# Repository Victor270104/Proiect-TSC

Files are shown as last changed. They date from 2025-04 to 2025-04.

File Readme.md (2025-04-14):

# OpenBook

**Autor:** Sandu Victor, 332CC

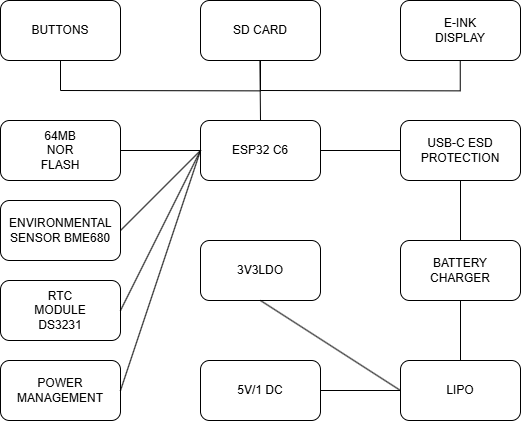
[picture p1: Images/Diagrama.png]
Diagrama Proiect


---

## 1. Descriere generală

Acest proiect propune o platformă hardware pentru dezvoltarea de aplicații IoT și afișare e-paper, cu consum redus de energie. Elementul central este microcontrollerul **ESP32-C6-WROOM-1**, care oferă conectivitate Wi-Fi 6 și Bluetooth Low Energy. Sistemul este proiectat pentru a funcționa atât conectat la USB-C, cât și alimentat de la o baterie Li-Po.

---

## 2. Caracteristici cheie

- **Alimentare prin USB-C**: Simplifică programarea și încărcarea bateriei.
- **Microcontroller ESP32-C6**: Include nucleu RISC-V, Wi-Fi 6, BLE și memorie flash internă de 8MB.
- **Senzori integrați**: BME688 (temperatură, umiditate, presiune, gaze) și DS3231 (ceas de timp real).
- **Stocare suplimentară**:
  - Card SD (SPI)
  - Memorie NOR Flash (W25Q512)
- **Afișaj E-Paper**: Consum ultra-redus, actualizare doar la nevoie.
- **Monitorizare baterie**: MAX17048 pentru nivelul de încărcare.

---

## 3. Structură hardware (sumar)

- **USB-C** și protecții ESD (varistori, diodă TVS).
- **Circuit încărcare Li-Po** cu MCP73831.
- **Regulator LDO** pentru 3.3V stabil.
- **Microcontrollerul ESP32-C6-WROOM-1** (SPI, I2C, GPIO).
- **Senzori**:
  - BME688 (I2C)
  - DS3231 (I2C)
- **Memorii**:
  - Card SD (SPI)
  - W25Q512 (SPI)
- **E-Paper** cu driver SPI și alimentare comutabilă (MOSFET).
- **Butoane** de RESET și BOOT.

*(Diagrama de mai sus este inclusă din `Images/Diagrama.png`.)*

---

## 4. Bill of Materials (BOM)

| Component  | Supplier Link | Datasheet |
|---|---|---|
| 112A-TAAR-R03 | [Model](https://store.comet.srl.ro/Catalogue/Product/43497/) | [Datasheet](https://www.snapeda.com/parts/112A-TAAR-R03/Attend/datasheet/) |
| 744043680 | [Model](https://ro.mouser.com/ProductDetail/Wurth-Elektronik/744043680?qs=PGXP4M47uW6VkZq%252BkzjrHA%3D%3D) | [Datasheet](https://www.we-online.com/components/products/datasheet/744043680.pdf) |
| BD5229G-TR | [Model](https://componentsearchengine.com/part-view/BD5229G-TR/ROHM%20Semiconductor) | [Datasheet](https://fscdn.rohm.com/en/products/databook/datasheet/ic/power/voltage_detector/bd52xxg-e.pdf) |
| Capacitor 0402 | [Model](https://ro.mouser.com/c/passive-components/capacitors/ceramic-capacitors/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) | [Datasheet](https://componentsearchengine.com/Datasheets/2/CC0402MRX5R5BB106.pdf) |
| CPH3225A | [Model](https://www.snapeda.com/parts/CPH3225A/Seiko+Instruments/view-part/?ref=snap) | [Datasheet](https://www.snapeda.com/parts/CPH3225A/Seiko%20Instruments/datasheet/) |
| Custom Button | [Model](https://industry.panasonic.com/global/en/products/control/switch/light-touch/number/evqpuj02k) | [Datasheet](https://industry.panasonic.com/global/en/downloads?tab=catalog&small_g_cd=203&part_no=EVQPUJ02K) |
| DS3231SN | [Model](https://www.snapeda.com/parts/DS3231SN%23/Analog+Devices/view-part/?ref=eda) | [Datasheet](https://www.snapeda.com/parts/DS3231SN%23/Analog%20Devices/datasheet/) |
| ESP32 WROVER 0805 Capacitor | [Model]() | [Datasheet]() |
| ESP32 WROVER BME680 Sensor | [Model](https://www.snapeda.com/parts/BME680/Bosch/view-part/?welcome=home) | [Datasheet](https://www.bosch-sensortec.com/media/boschsensortec/downloads/datasheets/bst-bme680-ds001.pdf) |
| ESP32 WROVER MCP73831 Power Management | [Model](https://www.snapeda.com/parts/BME680/Bosch/view-part/?welcome=home) | [Datasheet](https://www.snapeda.com/parts/MCP73831T-2ACI/OT/Microchip/datasheet/) |
| ESP32C6 Varistor 1812 | [Model]() | [Datasheet]() |
| ESP32C6 WROOM-1-N8| [Model](https://www.snapeda.com/parts/ESP32-C6-WROOM-1-N8/Espressif+Systems/view-part/?ref=eda) | [Datasheet](https://www.snapeda.com/parts/ESP32-C6-WROOM-1-N8/Espressif%20Systems/datasheet/) |
| FH34SRJ-24S-0.5SH | [Model](https://ro.mouser.com/ProductDetail/Hirose-Connector/FH34SRJ-24S-0.5SH99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) | [Datasheet](https://www.snapeda.com/parts/FH34SRJ-24S-0.5SH(99)/Hirose%20Connector/datasheet/) |
| LED Chip 0603 | [Model](https://www.snapeda.com/parts/KP-1608SURCK/Kingbright/view-part/?ref=search&t=LED%200603) | [Datasheet](https://www.snapeda.com/parts/KP-1608SURCK/Kingbright/datasheet/) |
| MAX17048G+T10 | [Model](https://www.snapeda.com/parts/MAX17048G+T10/Analog+Devices/view-part/?ref=eda) | [Datasheet](https://www.snapeda.com/parts/MAX17048G+T10/Analog%20Devices/datasheet/) |
| MBR0530 Schottky Diode | [Model](https://www.snapeda.com/parts/MBR0530/Onsemi/view-part/?ref=snap) | [Datasheet](https://www.snapeda.com/parts/MBR0530/ON%20Semiconductor/datasheet/) |
| PGB1010603MR | [Model](https://www.snapeda.com/parts/PGB1010603MR/Littelfuse/view-part/?ref=eda) | [Datasheet](https://www.snapeda.com/parts/PGB1010603MR/Littelfuse%20Inc./datasheet/) |
| QWIIC Connector | [Model](https://www.snapeda.com/parts/PRT-14417/SparkFun/view-part/) | [Datasheet](https://www.snapeda.com/parts/PRT-14417/SparkFun%20Electronics/datasheet/) |
| RCL CPOL 3528 | [Model](https://www.snapeda.com/parts/CPH3225A/Seiko+Instruments/view-part/?ref=eda) | [Datasheet](https://s3.amazonaws.com/snapeda/datasheet/TAJB475K025RNJ_AVX.pdf) |
| Resistor 0402 | [Model](https://grabcad.com/library/resistor-0402-1) | [Datasheet](https://www.yageo.com/upload/media/product/products/datasheet/rchip/PYu-RC_Group_51_RoHS_L_12.pdf) |
| SI1308EDL-T1-GE3 MOSFET | [Model](https://www.snapeda.com/parts/SI1308EDL-T1-GE3/Vishay+Siliconix/view-part/?welcome=home&ref=eda) | [Datasheet](https://www.snapeda.com/parts/SI1308EDL-T1-GE3/Vishay%20Siliconix/datasheet/) |
| SJ | [Model](https://grabcad.com/library/solder-jumpers-1) | [Datasheet]() |
| USB4110-GF-A | [Model](https://componentsearchengine.com/part-view/USB4110-GF-A/GCT%20(GLOBAL%20CONNECTOR%20TECHNOLOGY)) | [Datasheet](https://gct.co/files/drawings/usb4110.pdf) |
| USBLC6-2SC6Y | [Model](https://www.snapeda.com/parts/USBLC6-2SC6Y/STMicroelectronics/view-part/?welcome=home&ref=eda) | [Datasheet](https://www.snapeda.com/parts/USBLC6-2SC6Y/STMicroelectronics/datasheet/) |
| W25Q512JVEIQ | [Model](https://www.snapeda.com/parts/W25Q512JVEIQ/Winbond+Electronics/view-part/?ref=eda) | [Datasheet](https://www.winbond.com/resource-files/W25Q512JV%20SPI%20RevB%2006252019%20KMS.pdf) |
| XC6220A331MR-G | [Model](https://componentsearchengine.com/part-view/XC6220A331MR-G/Torex) | [Datasheet](https://product.torexsemi.com/system/files/series/xc6220.pdf) |

## 5. Mapare pini ESP32-C6

| Component | ESP32-C6 Pin(s) | Interface | Purpose |
|---|---|---|---|
| **E-Paper Display** | IO7 (MOSI), IO6 (SCK), IO10 (CS), IO5 (DC), IO23 (RST), IO3 (BUSY) | SPI | Transfers image data to the display and controls its state. |
| **MicroSD Card** | IO7 (MOSI), IO6 (SCK), IO4 (SS_SD), IO2 (MISO) | SPI | Allows storage and retrieval of e-book files. |
| **Environmental Sensor (BME688)** | IO21 (SDA), IO22 (SCL) | I2C | Reads temperature, humidity, pressure, and air quality data. |
| **RTC Module (DS3231)**  | IO21 (SDA), IO22 (SCL), IO18 (RST), IO1 (32KHz), IO0 (INT_RTC) | I2C | Keeps track of time even when ESP32 is off. |
| **External NOR Flash** | IO11 (CS), IO6 (SCK), IO2 (MISO), IO7 (MOSI) | SPI | Provides additional storage for application data. |
| **Battery Monitoring** | IO21 (SDA), IO22 (SCL) | I2C | Reads battery voltage and charge status. |
| **USB-C Connection** | GPIOs through voltage regulation | USB | Powers and programs the ESP32-C6. |
| **Control Buttons** | IO9 (BOOT), IO15 (CHANGE), EN (RESET) | GPIO | User input for device interactions. |
|

## 6. Consum de energie (exemplu)

| Component | Current Draw (mA) | Voltage (V) | Power (mW) |
|---|---|---|---|
| ESP32-C6 (Wi-Fi active)  |200 |3.3 |660
| E-Paper Display (Updating) | 40 | 3.3 | 132 |
| BME688 Sensor (Measuring)| 3.1 | 3.3 | 10.23 |
| RTC Module (Active) | 0.15 | 3.3 | 0.495 |
| SD Card (Active) | 50 | 3.3 | 165 |
| Externar NOR Flash | 25 | 3.3 | 82.5 |
| Total Estimated Power Consumption | ~318.5mA | 3.3 | 1050.72 |

## 7. Descriere functionala hardware 

###  Arhitectura Hardware

Sistemul este bazat pe microcontrollerul **ESP32-C6-WROOM-1**, cu conectivitate Wi-Fi 6 și BLE, gândit pentru funcționare autonomă și consum redus de energie. Dispozitivul este alimentat de la o baterie Li-Po și poate fi programat prin USB-C. Componentele sunt interconectate prin SPI, I2C și GPIO.

---

### Alimentare și management baterie

- **USB-C Connector & ESD Protection**  
  Conector: `USB4110-GF-A`  
  Protecție ESD: `USBLC6-2SC6Y`

- **LDO Voltage Regulator**  
  Asigură 3.3V stabil pentru întreaga placă

- **Li-Po Battery Charger**  
  MCP73831 – circuit dedicat pentru încărcarea bateriei

- **Battery Gauge (MAX17048)**  
  Măsoară nivelul bateriei și comunică prin I2C

---

### Microcontroller principal

- **ESP32-C6-WROOM-1-N8**  
  RISC-V MCU cu Wi-Fi 6, BLE, 8MB flash intern  
  Rol: control central, comunicare cu senzori, logare, afișare

---

### Stocare

- **SD Card** – pentru loguri de date, firmware, fișiere
- **W25Q512 NOR Flash** – pentru memorie suplimentară SPI (64Mbit)

---

### Senzori & Ceas

- **BME688** – măsoară temperatură, umiditate, presiune și gaze (I2C)
- **DS3231** – ceas de timp real, cu precizie ridicată (I2C)

---

### Afișaj

- **E-Paper Driver + Conector**  
  Conectat prin SPI, controlat de ESP32  
  Alimentarea este comutabilă cu un MOSFET (SI1308EDL)

---

### Control și testare

- **Reset / Boot Buttons**
- **Qwiic/Stemma QT Connector** – extensii I2C
- **Test Pads** – debugging ușor

---

### Protecții

- **TVS Diodes**: `PGB1010603MR` – protecție ESD pe linii sensibile
- **Varistori**: protecție la supratensiuni

---

## 9. Note Adiționale de Proiectare

### Ajustări ale Footprint-urilor

- **Diode (SMD-Hole)**: Footprint-ul inițial avea orificiile pad-urilor prea mici, ceea ce ar fi putut cauza probleme la lipire. Dimensiunea pad-urilor a fost actualizată la **35mil x 190mil** pentru a asigura o producibilitate bună și o conexiune electrică fiabilă.

- **U4 – MAX17048G+T10**: Calea de alimentare VBAT a fost proiectată cu o lățime de **0,3 mm**, pe baza constrângerilor de implementare. Totuși, în footprint, pinii aveau numai **0,27 mm**, cauzând asimetrie și rutare inconsistentă. Dimensiunile pinilor au fost ajustate pentru a se potrivi cu lățimea traseului și a menține simetria designului.

---

### Rutare & Plan de Masă

- **Traseele de alimentare** au fost rutate exclusiv pe stratul superior (Top Layer), necesitând aproximativ **150 de via-uri** pentru a permite rutarea semnalelor pe stratul inferior (Bottom Layer).
- **Planul de masă (GND)** a fost adăugat după ce rutarea a fost finalizată, aplicându-se atât pe stratul superior, cât și pe cel inferior, pentru a obține o împământare cu impedanță redusă și pentru a diminua interferențele EMI.

---

### Poziționarea Componentelor

- **Porturile externe** au fost aliniate cu atenție în raport cu carcasa personalizată OpenBook, pentru a asigura o potrivire corectă și acces ușor.
- **Pad-urile de test (TP)** au fost plasate în apropierea marginilor plăcii și în zone accesibile, pentru a facilita depanarea și testarea.
- **Condenzatoarele de decuplare 100nF** au fost poziționate cât mai aproape de pinii de alimentare ai circuitelor integrate, în conformitate cu practicile standard de reducere a zgomotului.

---

### Probleme de Schematice & Modele 3D

- **Net „GND1”**: A apărut în schematică un net denumit „GND1”, însă acesta nu era vizibil și nu era funcțional conectat la masă. Se presupune că a fost un artefact apărut în timpul procesului de proiectare.
- **Ordinea pinilor la componente 3D**: După finalizarea rutării, actualizarea modelelor 3D a inversat ordinea pinilor la anumite componente cu 2 pini, rupând conexiunile existente. S-a rezolvat prin rotirea acelor modele cu **180°** și realinierea pinilor.

---

### Carcasă & Integrare 3D

- A fost creată o versiune alternativă a carcasei OpenBook, care include o **culoare personalizată** pentru un aspect unic.
- Componentele 3D au fost importate în două moduri diferite, în funcție de frecvența cu care apăreau în schematică.

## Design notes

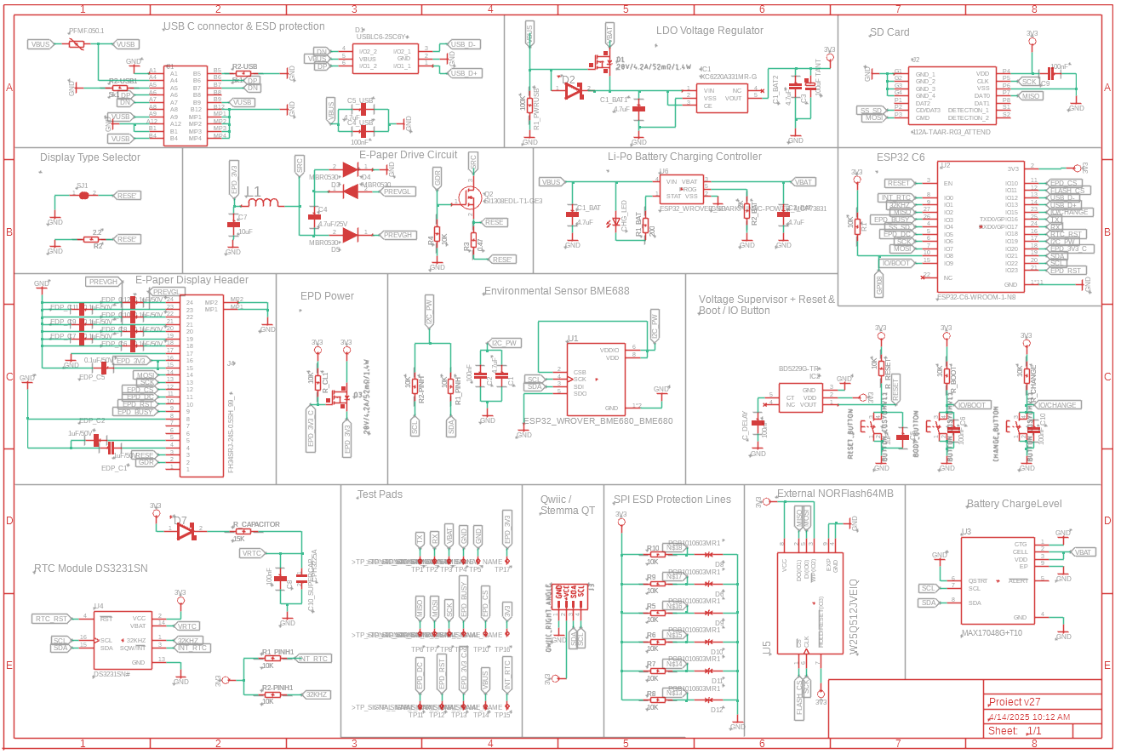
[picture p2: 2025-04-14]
Images/Schematic.png

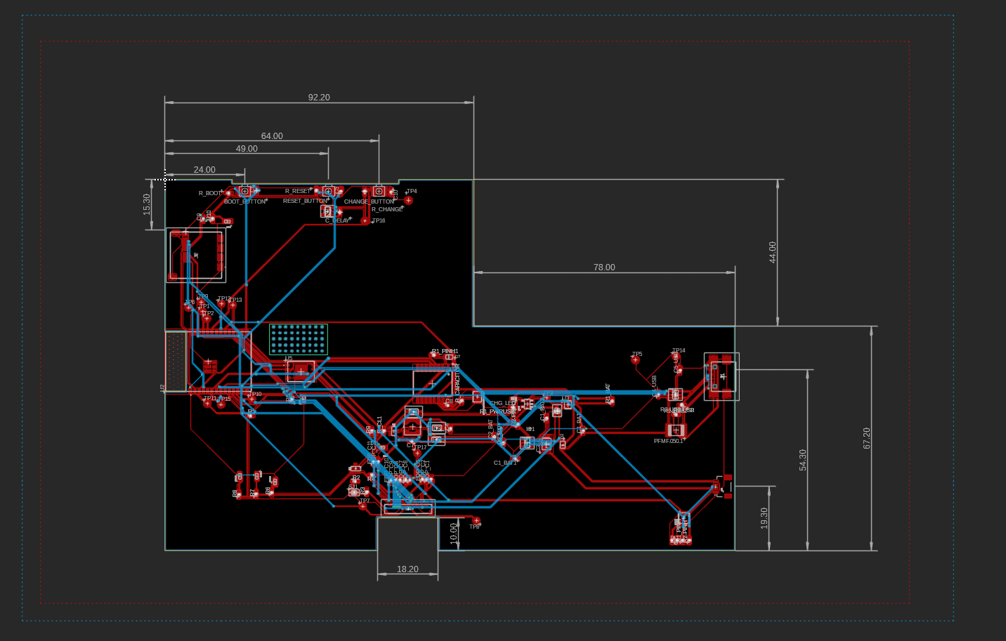
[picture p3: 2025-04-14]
Images/2D.png

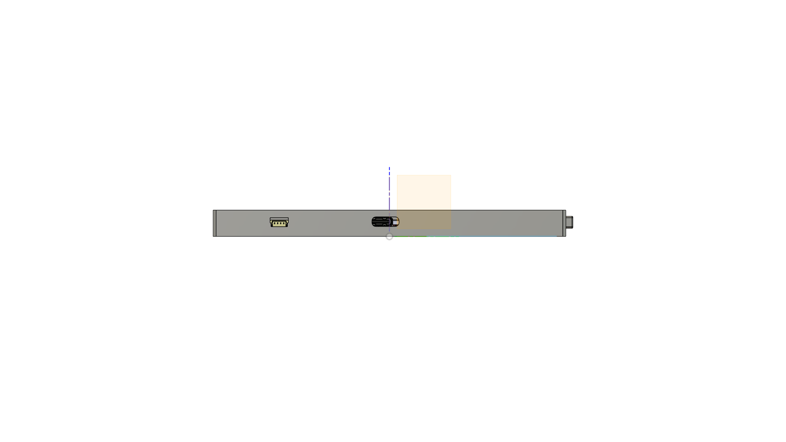
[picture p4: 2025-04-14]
Images/ports.png

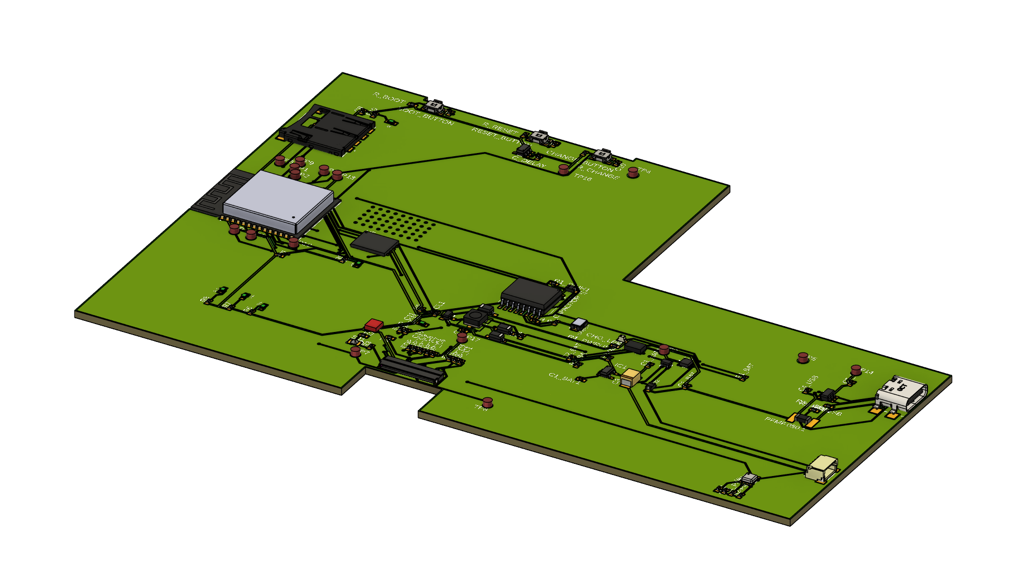
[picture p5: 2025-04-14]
Images/3D.png

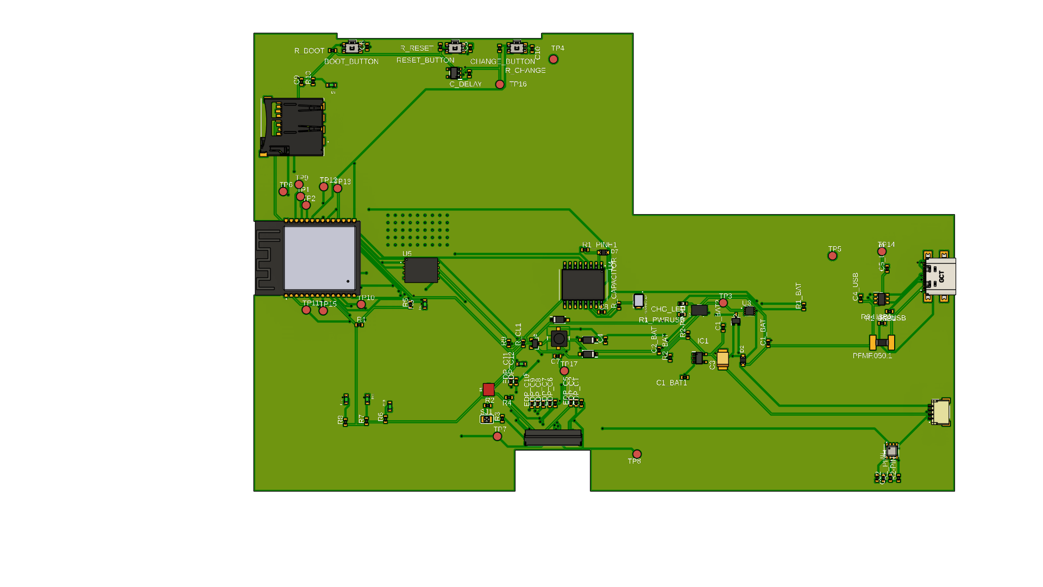
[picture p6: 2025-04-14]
Images/3D TOP.png

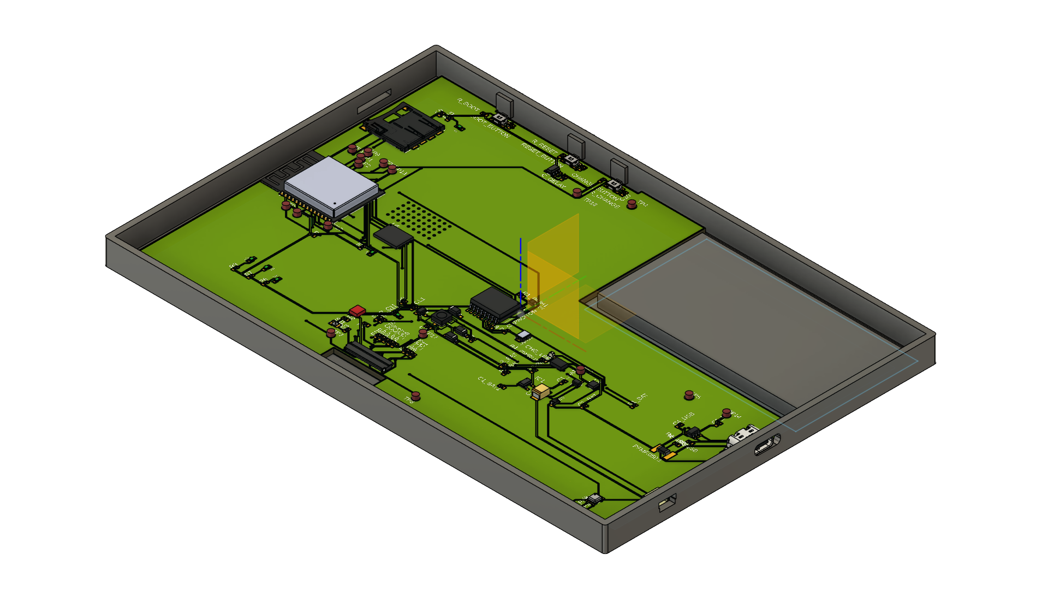
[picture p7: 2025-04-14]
Images/enclosed.png

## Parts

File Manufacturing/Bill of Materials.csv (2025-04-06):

Qty | Value | Device | Package | Parts | Description | ARROW_PART_NUMBER | ARROW_PRICE-STOCK | AVAILABILITY | CHECK_PRICES | COPYRIGHT | DESCRIPTION | HEIGHT | MANUFACTURER_NAME | MANUFACTURER_PART_NUMBER | MF | MFR_NAME | MOUSER_PART_NUMBER | MOUSER_PRICE-STOCK | MOUSER_TESTING_PART_NUMBER | MOUSER_TESTING_PRICE-STOCK | MP | PACKAGE | POPULARITY | PRICE | PROD_ID | PURCHASE-URL | SNAPEDA_LINK | SPICEMODEL | SPICEPREFIX | VALUE
1 |  | ADAFRUIT_LEDCHIP-LED0603 | ADAFRUIT_CHIP-LED0603 | CHG_LED | LED
1 |  | SJ | SJ | SJ1 | SMD solder JUMPER |  |  |  |  |  |  |  |  |  |  |  |  |  |  |  |  |  | 3
8 | 0.1uF/50V | EAGLE-LTSPICE_C | ESP32_WROVER_EAGLE-LTSPICE_C0402 | EDP_C5, EDP_C6, EDP_C7, EDP_C8, EDP_C9, EDP_C10, EDP_C11, EDP_C12 | CAPACITOR, European symbol
1 | 0.47 | ESP32_WROVER_EAGLE-LTSPICE_R | ESP32_WROVER_EAGLE-LTSPICE_R0402 | R3 | RESISTOR, European symbol
1 | 100K | ESP32_WROVER_EAGLE-LTSPICE_R | ESP32_WROVER_EAGLE-LTSPICE_R0402 | R1_PWRUSB | RESISTOR, European symbol
7 | 100nF | EAGLE-LTSPICE_C | ESP32_WROVER_EAGLE-LTSPICE_C0402 | C2, C4_USB, C6, C8, C9, C10, C_DELAY | CAPACITOR, European symbol
1 | 100uF TANT | RCL_CPOL-EUCT3528 | RCL_CT3528 | C3 | POLARIZED CAPACITOR, European symbol |  |  |  |  |  |  |  |  |  |  |  |  |  |  |  |  |  | 0 |  |  |  |  |  | C
16 | 10K | ESP32_WROVER_EAGLE-LTSPICE_R | ESP32_WROVER_EAGLE-LTSPICE_R0402 | R1, R1_PINH, R1_PINH1, R2-PINH, R2-PINH1, R4, R5, R6, R7, R8, R9, R10, R_BOOT, R_CHANGE, R_CL1, R_RESET | RESISTOR, European symbol
1 | 10uF | ESP32_WROVER_EAGLE-LTSPICE_CC0402 | ESP32_WROVER_EAGLE-LTSPICE_C0402 | C7 | CAPACITOR, European symbol |  |  |  |  |  |  |  |  |  |  |  |  |  |  |  |  |  |  |  |  |  |  | NONE | C
1 | 112A-TAAR-R03_ATTEND | 112A-TAAR-R03_ATTEND | 112ATAARR03ATTEND | J2 | Micro SD Card Socket, Push-Push Type, Top Mount, SMT, H=1.83mm, 10u |  |  |  |  |  | Micro SD Card Socket | Push-Push Type | Top Mount | SMT | H=1.83mm | 10u | 1.9mm | ATTEND | 112A-TAAR-R03 ATTEND
1 | 15K | ESP32_WROVER_EAGLE-LTSPICE_R | ESP32_WROVER_EAGLE-LTSPICE_R0402 | R_CAPACITOR | RESISTOR, European symbol
1 | 1uF | EAGLE-LTSPICE_C | ESP32_WROVER_EAGLE-LTSPICE_C0402 | C5 | CAPACITOR, European symbol
2 | 1uF/50V | EAGLE-LTSPICE_C | ESP32_WROVER_EAGLE-LTSPICE_C0402 | EDP_C1, EDP_C2 | CAPACITOR, European symbol
1 | 2.2 | ESP32_WROVER_EAGLE-LTSPICE_R | ESP32_WROVER_EAGLE-LTSPICE_R0402 | R2 | RESISTOR, European symbol
1 | 200 | ESP32_WROVER_EAGLE-LTSPICE_R | ESP32_WROVER_EAGLE-LTSPICE_R0402 | R1_BAT | RESISTOR, European symbol
2 | 20V/4.2A/52m?/1.4W | ESP32_WROVER_SPARKFUN-DISCRETESEMI_MOSFET_PCH-DMG2305UX-7 | ESP32_WROVER_SPARKFUN-DISCRETESEMI_SOT23-3 | Q1, Q3 | P-channel MOSFETs |  |  |  |  |  |  |  |  |  |  |  |  |  |  |  |  |  |  |  | TRAN-14388 |  |  |  |  | 20V/4.2A/52m?/1.4W
1 | 2K | ESP32_WROVER_EAGLE-LTSPICE_R | ESP32_WROVER_EAGLE-LTSPICE_R0402 | R2_BAT | RESISTOR, European symbol
4 | 4.7uF | EAGLE-LTSPICE_C | ESP32_WROVER_EAGLE-LTSPICE_C0402 | C1, C1_BAT1, C1_BAT2, C5_USB | CAPACITOR, European symbol
2 | 4.7uF | ESP32_WROVER_EAGLE-LTSPICE_CC0402 | ESP32_WROVER_EAGLE-LTSPICE_C0402 | C1_BAT, C2_BAT | CAPACITOR, European symbol |  |  |  |  |  |  |  |  |  |  |  |  |  |  |  |  |  |  |  |  |  |  | NONE | C
1 | 4.7uF/25V | ESP32_WROVER_EAGLE-LTSPICE_CC0402 | ESP32_WROVER_EAGLE-LTSPICE_C0402 | C4 | CAPACITOR, European symbol |  |  |  |  |  |  |  |  |  |  |  |  |  |  |  |  |  |  |  |  |  |  | NONE | C
2 | 5k1 | ESP32_WROVER_EAGLE-LTSPICE_R | ESP32_WROVER_EAGLE-LTSPICE_R0402 | R2-USB, R2-USB1 | RESISTOR, European symbol
1 | 744043680IND_4828-WE-TPC_WRE | 744043680IND_4828-WE-TPC_WRE | IND_4828-WE-TPC_WRE | L1 |  |  |  |  |  | Copyright (C) 2024 Ultra Librarian. All rights reserved. |  |  |  | 744043680 |  | Wurth Electronics
1 | BD5229G-TR | BD5229G-TR | SOT95P280X125-5N | IC2 | Voltage Detector with Adjustable Delay Time: CMOS processes are utilized to develop high precision, low current consumption CMOS reset ICs that allow arbitrary setting of the delay time. The extensive lineup includes both Nch Open Drain and CMOS output types in a wide range of detection voltages (from 2.3V to 6.0V, in 0.1V steps), enabling selection of the ideal solution based on customer requirements. In addition, the entire series is of course both lead-free and RoHS-compliant. |  |  |  |  |  | Voltage Detector with Adjustable Delay Time: CMOS processes are utilized to develop high precision | low current consumption CMOS reset ICs that allow arbitrary setting of the delay time. The extensive lineup includes both Nch Open Drain and CMOS output types in a wide range of detection voltages (from 2.3V to 6.0V | in 0.1V steps) | enabling selection of the ideal solution based on customer requirements. In addition | the entire series is of course both lead-free and RoHS-compliant. | 1.25mm | ROHM Semiconductor | BD5229G-TR |  |  | 755-BD5229G-TR | https://www.mouser.co.uk/ProductDetail/ROHM-Semiconductor/BD5229G-TR?qs=4kLU8WoGk0vvnhrrYwdszw%3D%3D
3 | BUTTON_CUSYOMV11 | BUTTON_CUSYOMV11 | MYBUTTON | BOOT_BUTTON, CHANGE_BUTTON, RESET_BUTTON
1 | CPH3225A | CPH3225A | CAPCP3225X100N | C10_SUPERCAP | Cap 0.011F 3.3V 1210 Flat Check availability |  |  | Not in stock | https://www.snapeda.com/parts/CPH3225A/Seiko+Instruments/view-part/?ref=eda |  | 11 mF (EDLC) Supercapacitor 3.3 V 1210 (3225 Metric) - - |  |  |  | Seiko Instruments |  |  |  |  |  | CPH3225A | 1210 Seiko |  | None |  | https://www.snapeda.com/api/url_track_click_mouser/?unipart_id=562593&manufacturer=Seiko Instruments&part_name=CPH3225A&search_term=None | https://www.snapeda.com/parts/CPH3225A/Seiko+Instruments/view-part/?ref=snap
1 | DS3231SN# | DS3231SN# | SOIC127P1032X265-16N | U4 | Real Time Clock Serial 16-Pin SOIC W T/R Check availability |  |  | In Stock | https://www.snapeda.com/parts/DS3231SN%23/Analog+Devices/view-part/?ref=eda |  | Extremely Accurate I2C-Integrated RTC/TCXO/Crystal |  |  |  | Analog Devices |  |  |  |  |  | DS3231SN# | SOIC-16 Maxim |  | None |  | https://www.snapeda.com/api/url_track_click_mouser/?unipart_id=99048&manufacturer=Analog Devices&part_name=DS3231SN#&search_term=None | https://www.snapeda.com/parts/DS3231SN%23/Analog+Devices/view-part/?ref=snap
1 | ESP32-C6-WROOM-1-N8 | ESP32-C6-WROOM-1-N8 | XCVR_ESP32-C6-WROOM-1-N8 | U2 | Check availability |  |  | In Stock | https://www.snapeda.com/parts/ESP32-C6-WROOM-1-N8/Espressif+Systems/view-part/?ref=eda |  | Multiprotocol Modules ESP32-C6 module | Wi-Fi 6 in 2.4 GHz band | Bluetooth 5 | Zigbee 3.0 and Thread. ESP34-WROOM Compatible - ENGINEERING SAMPLE |  |  |  | Espressif Systems |  |  |  |  |  | ESP32-C6-WROOM-1-N8 | None |  | None |  |  | https://www.snapeda.com/parts/ESP32-C6-WROOM-1-N8/Espressif+Systems/view-part/?ref=snap
1 | ESP32C6_VARISTORCN1812 | ESP32C6_VARISTORCN1812 | ESP32C6_VARISTOR_CT/CN1812 | PFMF.050.1 | VARISTOR |  |  |  |  |  |  |  |  |  |  |  |  |  |  |  |  |  | 0
2 | ESP32_WROVER_AVX---SD0805S020S1R0_AVX_SD0805S020S1R0_0_0 | ESP32_WROVER_AVX---SD0805S020S1R0_AVX_SD0805S020S1R0_0_0 | ESP32_WROVER_AVX---SD0805S020S1R0_AVX_SD0805S020S1R0_0 | D2, D7 | Schottky Barrier Rectifier Diode
1 | ESP32_WROVER_BME680_BME680 | ESP32_WROVER_BME680_BME680 | ESP32_WROVER_BME680_PSON80P300X300X100-8N | U1 | Integrated Environmental Unit |  |  | Unavailable |  |  | Integrated Environmental Unit |  |  |  | Bosch Sensortec |  |  |  |  |  | BME680 | LGA-8 Bosch Tools |  | None
1 | ESP32_WROVER_SPARKFUN-IC-POWER_MCP73831 | ESP32_WROVER_SPARKFUN-IC-POWER_MCP73831 | ESP32_WROVER_SPARKFUN-IC-POWER_SOT23-5 | U6 | MCP73831T Li-Ion, Li-Pol Controller |  |  |  |  |  |  |  |  |  |  |  |  |  |  |  |  |  |  |  | IC-09995
1 | FH34SRJ-24S-0.5SH_99_ | FH34SRJ-24S-0.5SH_99_ | FH34SRJ24S05SH99 | J4 | (0.50mm) Surface Mount, Right Angle |  |  |  |  |  | 24 Position FFC | FPC Connector Contacts | (0.50mm) Surface Mount | Right Angle | 1.1mm | Hirose | FH34SRJ-24S-0.5SH(99) |  |  | 798-FH34SRJ24S05SH99 | https://www.mouser.co.uk/ProductDetail/Hirose-Connector/FH34SRJ-24S-0.5SH99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
1 | MAX17048G+T10 | MAX17048G+T10 | SON50P200X200X80-9N | U3 | Check availability |  |  | In Stock | https://www.snapeda.com/parts/MAX17048G+T10/Analog+Devices/view-part/?ref=eda |  | 3µA 1-Cell/2-Cell Fuel Gauge with ModelGauge |  |  |  | Analog Devices |  |  |  |  |  | MAX17048G+T10 | TDFN-8 Maxim |  | None |  | https://www.snapeda.com/api/url_track_click_mouser/?unipart_id=329239&manufacturer=Analog Devices&part_name=MAX17048G+T10&search_term=None | https://www.snapeda.com/parts/MAX17048G+T10/Analog+Devices/view-part/?ref=snap
3 | MBR0530 | MBR0530 | SOD3716X135N | D3, D4, D5 | ON SEMICONDUCTOR - MBR0530 - DIODE, SCHOTTKY, 0.5A, 30V, SOD-123 |  |  | In Stock | https://www.snapeda.com/parts/MBR0530/Onsemi/view-part/?ref=eda |  | Diode Schottky 30 V 500mA Surface Mount SOD-123 |  |  |  | ON Semiconductor |  |  |  |  |  | MBR0530 | SOD-123-2 ON Semiconductor |  | None |  | https://www.snapeda.com/api/url_track_click_mouser/?unipart_id=179458&manufacturer=ON Semiconductor&part_name=MBR0530&search_term=None | https://www.snapeda.com/parts/MBR0530/Onsemi/view-part/?ref=snap
6 | PGB1010603MR1 | PGB1010603MR1 | DIOC1608X36N | D6, D8, D9, D10, D11, D12 | Check availability
1 | QWIIC_RIGHT_ANGLE | QWIIC_CONNECTORJS-1MM | JST04_1MM_RA | J3 | SparkFun I2C Standard Qwiic Connector |  |  |  |  |  |  |  |  |  |  |  |  |  |  |  |  |  |  |  | CONN-13694 |  |  |  |  | QWIIC_RIGHT_ANGLE
1 | SAMACSYS_PARTS_USB4110-GF-A | SAMACSYS_PARTS_USB4110-GF-A | SAMACSYS_PARTS_USB4110GFA | J1 | CONN USB 2.0 TYPE-C R/A SMT |  |  |  |  |  | CONN USB 2.0 TYPE-C R/A SMT | 3.26mm | GCT (GLOBAL CONNECTOR TECHNOLOGY) | USB4110-GF-A |  |  | 640-USB4110-GF-A | https://www.mouser.co.uk/ProductDetail/GCT/USB4110-GF-A?qs=KUoIvG%2F9IlYiZvIXQjyJeA%3D%3D
1 | SI1308EDL-T1-GE3 | SI1308EDL-T1-GE3 | SOT65P210X110-3N | Q2 | MOSFET N-Ch 30V 1.5A TrenchFET SC70 Vishay Si1308EDL-T1-GE3 N-channel MOSFET Transistor, 1.5 A, 30 V, 3-Pin SC-70 |  |  | In Stock | https://www.snapeda.com/parts/SI1308EDL-T1-GE3/Vishay+Siliconix/view-part/?ref=eda |  | Si1308EDL-T1-GE3 N-channel MOSFET Transistor | 1.5 A | 30 V | 3-Pin SC-70 | Siliconix / Vishay SI1308EDL-T1-GE3 |  |  |  | Vishay Siliconix |  |  |  |  |  | SI1308EDL-T1-GE3 | SOT-323 Vishay Semiconductor |  | None |  | https://www.snapeda.com/api/url_track_click_mouser/?unipart_id=274603&manufacturer=Vishay Siliconix&part_name=SI1308EDL-T1-GE3&search_term=None | https://www.snapeda.com/parts/SI1308EDL-T1-GE3/Vishay+Siliconix/view-part/?ref=snap
17 | TP | TP | TP20R | TP1, TP2, TP3, TP4, TP5, TP6, TP7, TP8, TP9, TP10, TP11, TP12, TP13, TP14, TP15, TP16, TP17 | Test pad
1 | USBLC6-2SC6Y | USBLC6-2SC6Y | SOT95P280X145-6N | D1 | Low Cap. ESD Protection Auto SOT-23-6 STMicroelectronics USBLC6-2SC6Y, Dual Uni-Directional TVS Diode Array, 6-Pin SOT-23 |  |  | In Stock | https://www.snapeda.com/parts/USBLC6-2SC6Y/STMicroelectronics/view-part/?ref=eda |  | 17V Clamp 5A (8/20µs) Ipp Tvs Diode Surface Mount SOT-23-6 |  |  |  | STMicroelectronics |  |  |  |  |  | USBLC6-2SC6Y | SOT-23-6 STMicroelectronics |  | None |  |  | https://www.snapeda.com/parts/USBLC6-2SC6Y/STMicroelectronics/view-part/?ref=snap
1 | W25Q512JVEIQ | W25Q512JVEIQ | SON127P600X800X80-9N | U5 | Check availability |  |  | In Stock | https://www.snapeda.com/parts/W25Q512JVEIQ/Winbond+Electronics/view-part/?ref=eda |  | FLASH - NOR Memory IC 512Mb (64M x 8) SPI - Quad I/O 133 MHz 8-WSON (8x6) |  |  |  | Winbond Electronics |  |  |  |  |  | W25Q512JVEIQ | Package |  | None |  |  | https://www.snapeda.com/parts/W25Q512JVEIQ/Winbond+Electronics/view-part/?ref=snap
1 | XC6220A331MR-G | XC6220A331MR-G | SOT95P280X120-5N | IC1 | LDO Voltage Regulators |  |  |  |  |  | LDO Voltage Regulators | 1.2mm | Torex | XC6220A331MR-G |  |  | 865-XC6220A331MR-G | https://www.mouser.co.uk/ProductDetail/Torex-Semiconductor/XC6220A331MR-G?qs=AsjdqWjXhJ8ZSWznL1J0gg%3D%3D

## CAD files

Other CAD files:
Mechanical/Proiect3D.f3z

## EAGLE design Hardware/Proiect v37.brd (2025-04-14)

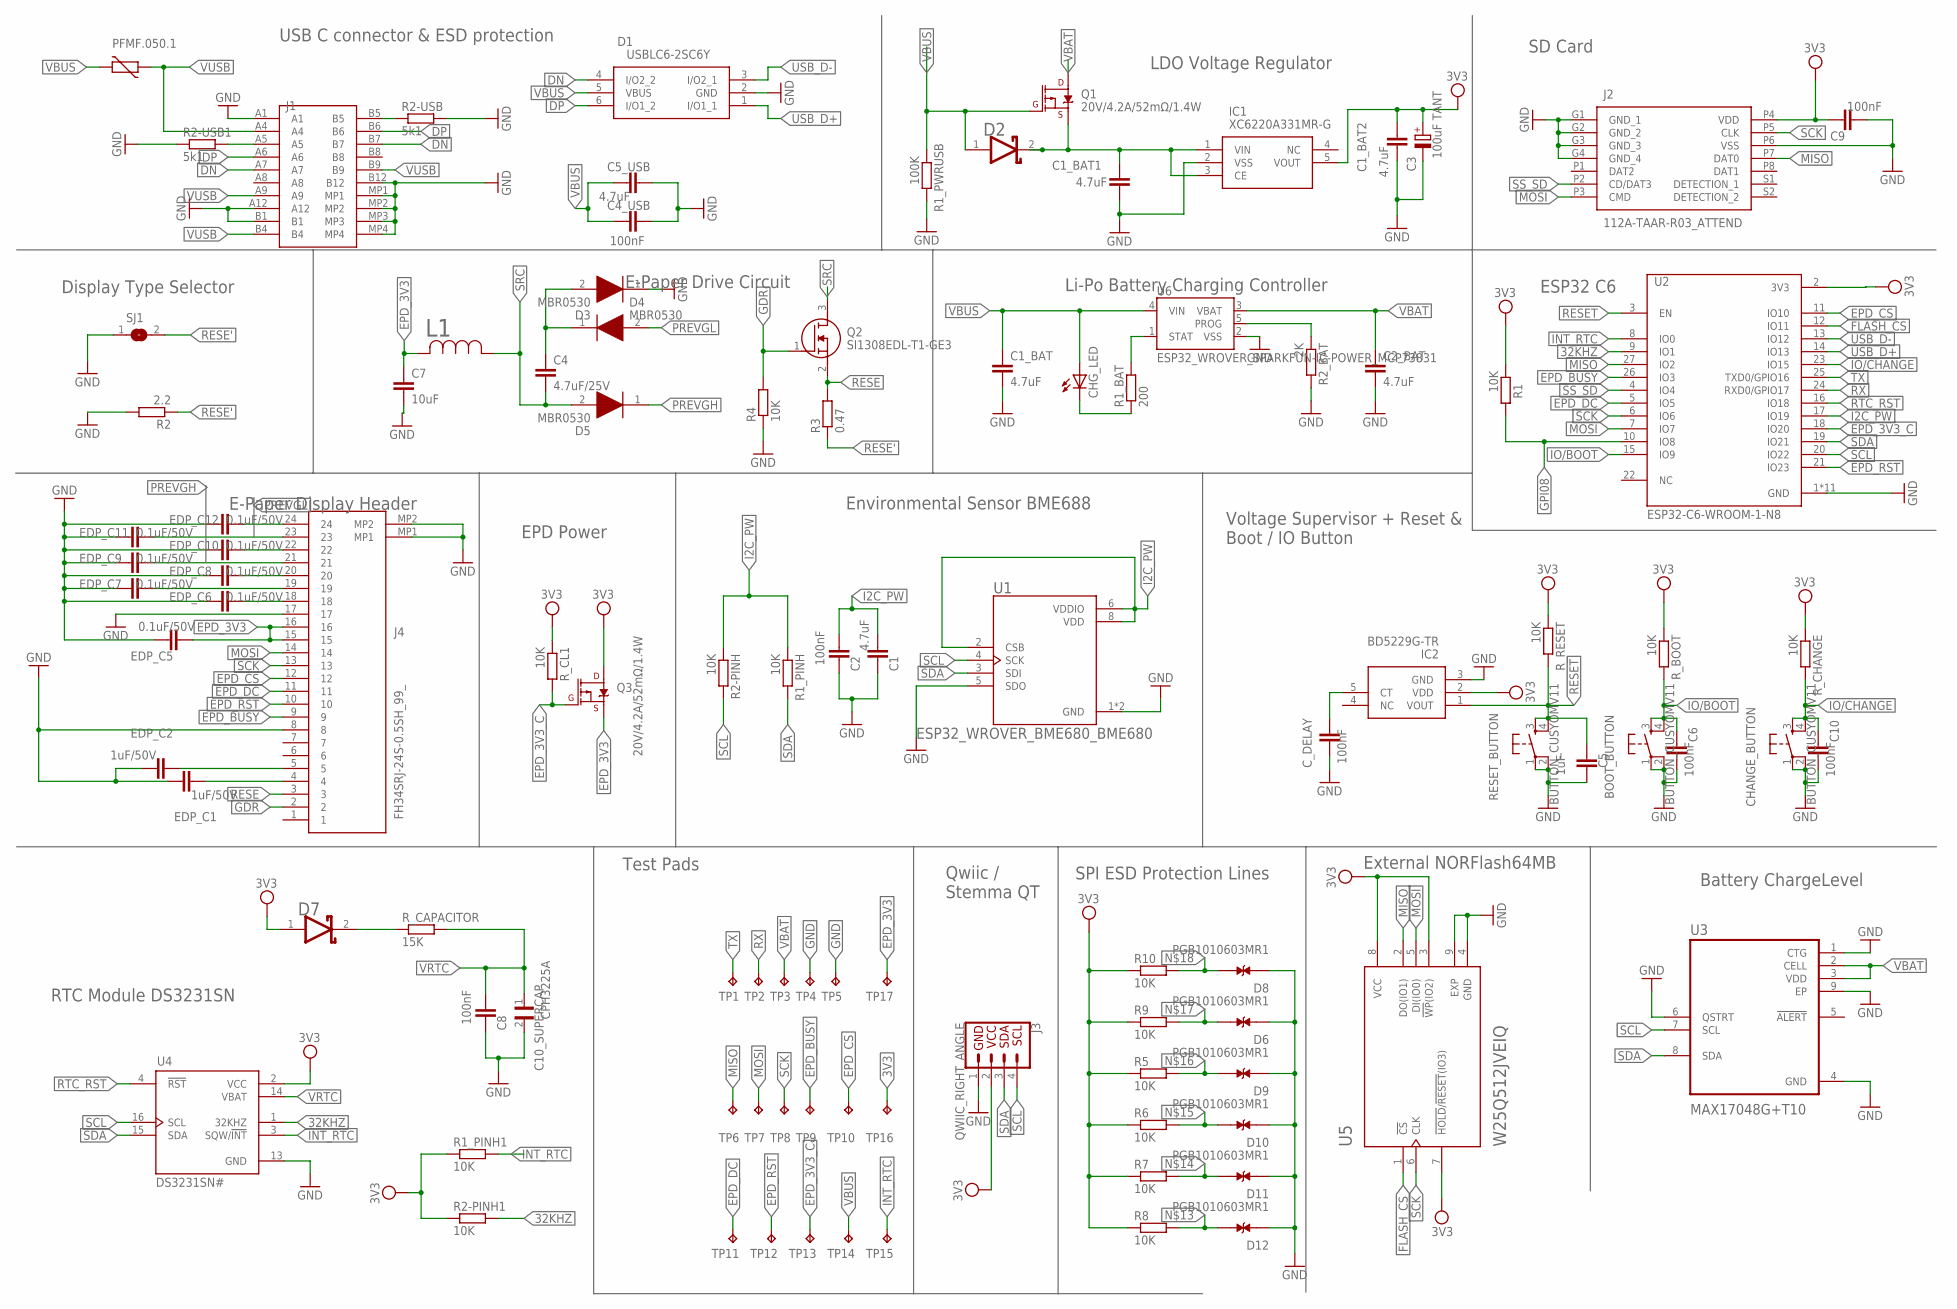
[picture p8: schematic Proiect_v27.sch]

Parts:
BOOT_BUTTON: BUTTON_CUSYOMV11; MYBUTTON
C1, C1_BAT, C1_BAT1, C1_BAT2, C2_BAT, C5_USB: 4.7uF; ESP32_WROVER_EAGLE-LTSPICE_C0402
C2, C4_USB, C6, C8, C9, C10: 100nF; ESP32_WROVER_EAGLE-LTSPICE_C0402
C3: 100uF TANT; RCL_CT3528
C4: 4.7uF/25V; ESP32_WROVER_EAGLE-LTSPICE_C0402
C5: 1uF; ESP32_WROVER_EAGLE-LTSPICE_C0402
C7: 10uF; ESP32_WROVER_EAGLE-LTSPICE_C0402
C10_SUPERCAP: CPH3225A; CAPCP3225X100N
CHANGE_BUTTON: BUTTON_CUSYOMV11; MYBUTTON
CHG_LED: ADAFRUIT_LEDCHIP-LED0603; ADAFRUIT_CHIP-LED0603
C_DELAY: 100nF; ESP32_WROVER_EAGLE-LTSPICE_C0402
D1: USBLC6-2SC6Y; SOT95P280X145-6N
D2, D7: ESP32_WROVER_AVX---SD0805S020S1R0_AVX_SD0805S020S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; ESP32_WROVER_AVX---SD0805S020S1R0_AVX_SD0805S020S1R0_0
D3, D4, D5: MBR0530; SOD3716X135N
D6, D8, D9, D10, D11, D12: PGB1010603MR1; DIOC1608X36N
EDP_C1, EDP_C2: 1uF/50V; ESP32_WROVER_EAGLE-LTSPICE_C0402
EDP_C5, EDP_C6, EDP_C7, EDP_C8, EDP_C9, EDP_C10, EDP_C11, EDP_C12: 0.1uF/50V; ESP32_WROVER_EAGLE-LTSPICE_C0402
IC1: XC6220A331MR-G; SOT95P280X120-5N
IC2: BD5229G-TR; SOT95P280X125-5N
J1: SAMACSYS_PARTS_USB4110-GF-A; SAMACSYS_PARTS_USB4110GFA
J2: 112A-TAAR-R03_ATTEND; 112ATAARR03ATTEND
J3: QWIIC_RIGHT_ANGLE; JST04_1MM_RA
J4: FH34SRJ-24S-0.5SH_99_; FH34SRJ24S05SH99
L1: 744043680IND_4828-WE-TPC_WRE; IND_4828-WE-TPC_WRE
PFMF.050.1: ESP32C6_VARISTORCN1812; ESP32C6_VARISTOR_CT/CN1812
Q1, Q3: 20V/4.2A/52mΩ/1.4W; ESP32_WROVER_SPARKFUN-DISCRETESEMI_SOT23-3
Q2: SI1308EDL-T1-GE3; SOT65P210X110-3N
R1, R1_PINH, R1_PINH1, R2-PINH, R2-PINH1, R4, R5, R6, R7, R8, R9, R10: 10K; ESP32_WROVER_EAGLE-LTSPICE_R0402
R1_BAT: 200; ESP32_WROVER_EAGLE-LTSPICE_R0402
R1_PWRUSB: 100K; ESP32_WROVER_EAGLE-LTSPICE_R0402
R2: 2.2; ESP32_WROVER_EAGLE-LTSPICE_R0402
R2-USB, R2-USB1: 5k1; ESP32_WROVER_EAGLE-LTSPICE_R0402
R2_BAT: 2K; ESP32_WROVER_EAGLE-LTSPICE_R0402
R3: 0.47; ESP32_WROVER_EAGLE-LTSPICE_R0402
RESET_BUTTON: BUTTON_CUSYOMV11; MYBUTTON
R_BOOT: 10K; ESP32_WROVER_EAGLE-LTSPICE_R0402
R_CAPACITOR: 15K; ESP32_WROVER_EAGLE-LTSPICE_R0402
R_CHANGE: 10K; ESP32_WROVER_EAGLE-LTSPICE_R0402
R_CL1: 10K; ESP32_WROVER_EAGLE-LTSPICE_R0402
R_RESET: 10K; ESP32_WROVER_EAGLE-LTSPICE_R0402
SJ1: SJ
TP1, TP2, TP3, TP4, TP5, TP6, TP7, TP8, TP9, TP10, TP11, TP12, TP13, TP14, TP15, TP16, TP17: TP; TP20R
U1: ESP32_WROVER_BME680_BME680; ESP32_WROVER_BME680_PSON80P300X300X100-8N
U2: ESP32-C6-WROOM-1-N8; XCVR_ESP32-C6-WROOM-1-N8
U3: MAX17048G+T10; SON50P200X200X80-9N
U4: DS3231SN#; SOIC127P1032X265-16N
U5: W25Q512JVEIQ; SON127P600X800X80-9N
U6: ESP32_WROVER_SPARKFUN-IC-POWER_MCP73831; ESP32_WROVER_SPARKFUN-IC-POWER_SOT23-5

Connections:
3V3: C1_BAT2.1, C3.+, C9.2, D7.1 (ANODE), IC1.5 (VOUT), IC2.2 (VDD), J2.P4 (VDD), J3.2, Q3.3 (D), R1.1, R1_PINH1.1, R2-PINH1.1, R5.1, R6.1, R7.1, R8.1, R9.1, R10.1, R_BOOT.1, R_CHANGE.1, R_CL1.1, R_RESET.1, TP16.TP, U2.2 (3V3), U4.2 (VCC), U5.3 (!WP!(IO2)), U5.7 (!HOLD!/!RESET!(IO3)), U5.8 (VCC)
32KHZ: R2-PINH1.2, U2.9 (IO1), U4.1 (32KHZ)
DN: D1.4 (I/O2_2), J1.A7, J1.B7
DP: D1.6 (I/O1_2), J1.A6, J1.B6
EPD_3V3: C7.1, EDP_C5.1, J4.15, J4.16, L1.2, Q3.2 (S), TP17.TP
EPD_3V3_C: Q3.1 (G), R_CL1.2, TP13.TP, U2.18 (IO20)
EPD_BUSY: J4.9, TP9.TP, U2.26 (IO3)
EPD_CS: J4.12, TP10.TP, U2.11 (IO10)
EPD_DC: J4.11, TP11.TP, U2.5 (IO5)
EPD_RST: J4.10, TP12.TP, U2.21 (IO23)
FLASH_CS: U2.12 (IO11), U5.1 (!CS)
GDR: J4.2, Q2.1 (G), R4.2
GND: BOOT_BUTTON.1, BOOT_BUTTON.2, C1.2, C1_BAT.2, C1_BAT1.2, C1_BAT2.2, C2.2, C2_BAT.2, C3.-, C4_USB.2, C5.2, C5_USB.2, C6.2, C7.2, C8.2, C9.1, C10.2, C10_SUPERCAP.2, CHANGE_BUTTON.1, CHANGE_BUTTON.2, C_DELAY.2, D1.2 (GND), D3.1 (K), D6.1, D8.1, D9.1, D10.1, D11.1, D12.1, EDP_C1.1, EDP_C2.2, EDP_C5.2, EDP_C6.2, EDP_C7.2, EDP_C8.2, EDP_C9.2, EDP_C10.2, EDP_C11.2, EDP_C12.2, IC1.2 (VSS), IC2.3 (GND), J1.A1, J1.A12, J1.B1, J1.B12, J1.MP1, J1.MP2, J1.MP3, J1.MP4, J2.G1 (GND_1), J2.G2 (GND_2), J2.G3 (GND_3), J2.G4 (GND_4), J2.P6 (VSS), J3.1, J4.8, J4.17, J4.MP1, J4.MP2, R1_PWRUSB.2, R2.2, R2-USB.2, R2-USB1.1, R2_BAT.2, R4.1, RESET_BUTTON.1, RESET_BUTTON.2, SJ1.1, TP4.TP, TP5.TP, U1.1 (GND), U1.5 (SDO), U1.7 (GND), U2.1 (GND), U2.28 (GND), U2.29_1 (GND), U2.29_2 (GND), U2.29_3 (GND), U2.29_4 (GND), U2.29_5 (GND), U2.29_6 (GND), U2.29_7 (GND), U2.29_8 (GND), U2.29_9 (GND), U3.1 (CTG), U3.4 (GND), U3.6 (QSTRT), U3.9 (EP), U4.13 (GND), U5.4 (GND), U5.9 (EXP), U6.2 (VSS)
GPI08: R1.2, U2.10 (IO8)
I2C_PW: C1.1, C2.1, R1_PINH.1, R2-PINH.1, U1.2 (CSB), U1.6 (VDDIO), U1.8 (VDD), U2.17 (IO19)
INT_RTC: R1_PINH1.2, TP15.TP, U2.8 (IO0), U4.3 (SQW/!INT)
IO/BOOT: BOOT_BUTTON.3, BOOT_BUTTON.4, C6.1, R_BOOT.2, U2.15 (IO9)
IO/CHANGE: C10.1, CHANGE_BUTTON.3, CHANGE_BUTTON.4, R_CHANGE.2, U2.23 (IO15)
MISO: J2.P7 (DAT0), TP6.TP, U2.27 (IO2), U5.2 (DO(IO1))
MOSI: J2.P3 (CMD), J4.14, TP7.TP, U2.7 (IO7), U5.5 (DI(IO0))
unnamed: EDP_C6.1, J4.18
unnamed: C1_BAT1.1, D2.2 (CATHODE), IC1.1 (VIN), IC1.3 (CE), Q1.2 (S)
unnamed: J1.A5, R2-USB1.2
unnamed: EDP_C7.1, J4.19
unnamed: EDP_C1.2, J4.4
unnamed: EDP_C2.1, J4.5
unnamed: EDP_C8.1, J4.20
unnamed: C_DELAY.1, IC2.5 (CT)
unnamed: EDP_C12.1, J4.24
unnamed: D7.2 (CATHODE), R_CAPACITOR.1
unnamed: J1.B5, R2-USB.1
unnamed: EDP_C10.1, J4.22
unnamed: D12.2, R8.2
unnamed: D11.2, R7.2
unnamed: D10.2, R6.2
unnamed: D9.2, R5.2
unnamed: D6.2, R9.2
unnamed: D8.2, R10.2
unnamed: R1_BAT.2, U6.1 (STAT)
unnamed: CHG_LED.C, R1_BAT.1
unnamed: R2_BAT.1, U6.5 (PROG)
unnamed: C4.1, D3.2 (A), D4.1 (K)
PREVGH: D5.1 (K), EDP_C9.1, J4.21
PREVGL: D4.2 (A), EDP_C11.1, J4.23
RESE: J4.3, Q2.2 (S), R3.2
RESE': R2.1, R3.1, SJ1.2
RESET: C5.1, IC2.1 (VOUT), RESET_BUTTON.3, RESET_BUTTON.4, R_RESET.2, U2.3 (EN)
RTC_RST: U2.16 (IO18), U4.4 (!RST)
RX: TP2.TP, U2.24 (RXD0/GPIO17)
SCK: J2.P5 (CLK), J4.13, TP8.TP, U2.6 (IO6), U5.6 (CLK)
SCL: J3.4, R2-PINH.2, U1.4 (SCK), U2.20 (IO22), U3.7 (SCL), U4.16 (SCL)
SDA: J3.3, R1_PINH.2, U1.3 (SDI), U2.19 (IO21), U3.8 (SDA), U4.15 (SDA)
SRC: C4.2, D5.2 (A), L1.1, Q2.3 (D)
SS_SD: J2.P2 (CD/DAT3), U2.4 (IO4)
TX: TP1.TP, U2.25 (TXD0/GPIO16)
USB_D+: D1.1 (I/O1_1), U2.14 (IO13)
USB_D-: D1.3 (I/O2_1), U2.13 (IO12)
VBAT: C2_BAT.1, Q1.3 (D), TP3.TP, U3.2 (CELL), U3.3 (VDD), U6.3 (VBAT)
VBUS: C1_BAT.1, C4_USB.1, C5_USB.1, CHG_LED.A, D1.5 (VBUS), D2.1 (ANODE), PFMF.050.1.2, Q1.1 (G), R1_PWRUSB.1, TP14.TP, U6.4 (VIN)
VRTC: C8.1, C10_SUPERCAP.1, R_CAPACITOR.2, U4.14 (VBAT)
VUSB: J1.A4, J1.A9, J1.B4, J1.B9, PFMF.050.1.1

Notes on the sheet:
USB C connector & ESD protection
LDO Voltage Regulator
SD Card
ESP32 C6
Li-Po Battery Charging Controller
E-Paper Drive Circuit
Display Type Selector
E-Paper Display Header
EPD Power
Environmental Sensor BME688
Voltage Supervisor + Reset & Boot / IO Button
Battery ChargeLevel
RTC Module DS3231SN
Test Pads
Qwiic / Stemma QT
SPI ESD Protection Lines
External NORFlash64MB

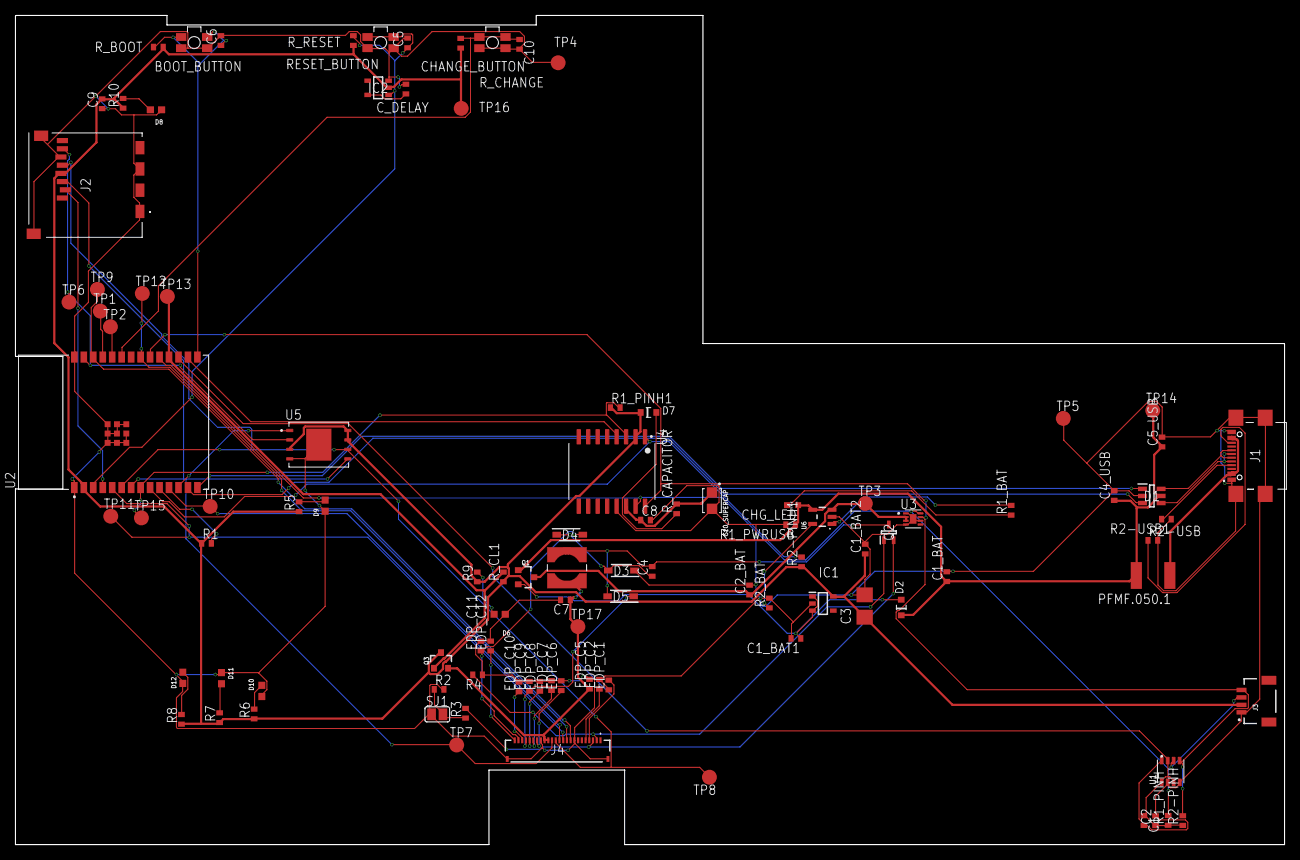
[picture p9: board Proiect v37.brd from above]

Board: 2 copper layers, 170.2 x 111.2 mm, 103 parts (0 on the bottom side), 61 nets.

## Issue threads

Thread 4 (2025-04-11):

[2D/3D] Incadrare nume componente

Alexx1612, 2025-04-11:
Numele componentelor de pe PCB-ul 2D trebuie aranjate astfel incat sa fie lizibile si sa nu se afle in exteriorul placii sau sa fie acoperite de  catre componente

Closed 2025-04-14.

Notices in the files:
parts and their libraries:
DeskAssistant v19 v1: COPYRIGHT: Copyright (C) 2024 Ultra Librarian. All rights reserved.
